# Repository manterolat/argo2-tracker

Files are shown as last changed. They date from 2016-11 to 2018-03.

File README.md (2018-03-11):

# Argo 2 Tracker

High Altitude Balloon tracker designed for the Argo 2 launch by the Near Space Program at the International School of Panama.

Tracker transmits temperature, pressure and humidity data, as well as location coordinates and other status information.

The GroundStation program shows any data received, along with signal strength and CRC checking. It can also upload new data to the online tracker at [HabHub](https://tracker.habhub.com).

Included are the PCB schematics (made in Eagle CAD) and software of the tracker and receiver, as well as the Ground Station program which runs on the tracking computer.

The software for the tracker and receiver is written in Arduino / C++, while the Ground Station written in Python.

## Table of Contents
 * [Parts and Components](#parts)
 * [Installation](#installation)
 * [Usage](#usage)
 * [Testing](#testing)
 * [Printed Circuit Boards](#pcbs)
 * [Launches](#launch)

## Parts and Components
### Tracker:
 * [Adafruit Feather M0](https://www.adafruit.com/product/269), or [Teensy 3.x](https://www.pjrc.com/store/teensy32.html) with [Feather adapter](https://www.adafruit.com/products/3200)
 * U-Blox NEO 6/7/8 Serial GPS module such as [this](https://www.amazon.com/Antenna-AeroQuad-Multirotor-Quadcopter-Aircraft/dp/B00RCP9MLY/)
 * ~~[MAX31855 thermocouple amplifier](https://www.adafruit.com/products/269) (and [thermocouple](https://www.adafruit.com/products/270))~~ Doesn't work
 * [BME280 module](https://www.adafruit.com/products/2652): Pressure, humidity and temperature sensor
 * RFM95W Transceiver

### Receiver:
 * [Adafruit Feather M0](https://www.adafruit.com/product/269)
 * RFM95W Transceiver
 * PCB SMA connector (if using SMA cable for antenna)

## Installation
To download the files in this repository run:

`git clone https://github.com/manterolat/argo2-tracker.git`

### Tracker:
#### Software
 * [Arduino IDE](https://www.arduino.cc/en/Main/Software) (1.6.0 and above should work)
 * If using *Teensy 3.x*: Install [Teensyduino](http://www.pjrc.com/teensy/teensyduino.html) (tested with Teensyduino 1.29)
 * If using *Feather M0*: follow [these](https://learn.adafruit.com/adafruit-feather-m0-basic-proto/setup) instructions

#### Arduino Libraries
 * [Adafruit Unified Sensor Driver](https://github.com/adafruit/Adafruit_Sensor)
 * [Adafruit BME280](https://github.com/adafruit/Adafruit_BME280_Library)
 * ~~Only with *Teensy* setup: [Adafruit MAX31855](https://github.com/adafruit/Adafruit-MAX31855-library) (version 1.0.3 or higher for SPI Transactions)~~ Doesn't work
 * If using *Teensy 3.x*: [RadioHead](https://github.com/PaulStoffregen/RadioHead) (Paul Stoffregen's version for Teensy)
 * If using *Feather M0*: [RadioHead](http://www.airspayce.com/mikem/arduino/RadioHead/) (Regular, updated version) 
 * ~~[TinyGPS++](https://github.com/mikalhart/TinyGPSPlus)~~ Broken for non-AVR chips: use [this](https://github.com/manterolat/argo2-tracker/files/601752/TinyGPSPlus.zip) modified version instead

### Receiver:
#### Software
 * [Arduino IDE](https://www.arduino.cc/en/Main/Software) (1.6.0 and above should work)

#### Arduino Libraries
 * [RadioHead](https://github.com/PaulStoffregen/RadioHead)

### Ground Station:
GroundStation runs on Python 2.7, and requires the following modules:
 * *crcmod* for CRC checking
 * *pyqrcode* for generating QR codes
 * *pyserial* for serial communication

To install these (using *pip*) run:

`pip install crcmod pyqrcode pyserial`

## Usage
After setting up the software and libary requirements you should be able to upload the tracker and receiver programs, as well as run the Ground Station.

### Tracker:
Open `/src/Argo2_Tracker/Argo2_Tracker.ino` in the Arduino IDE.

Before compiling and uploading to the Feather/Teensy make sure to configure the tracker by changing the following lines in the program: 
```C++
// Tracker callsign: change to your tracker's callsign
#define CALLSIGN "CHANGE_ME"

// Debug messages: uncomment the following line to enable printing to serial (for testing purposes)
//#define DEBUG

...

// Select either Teensy 3.x or Feather M0
#define TEENSY
//#define FEATHER
```

Leaving `#define DEBUG` uncommented will compile the Serial messages, which takes up space and cycles in the microcontroller.

Finally, select the board type and serial port in the Arduino IDE and upload.  

### Receiver:
Open `Argo2_Receiver.ino` with the Arduino IDE, then select the Feather M0 from the boards list and upload.

### Ground Station:
If running on macOS with Python 2 installed manually, double-clicking `GroundStation.py` should start the program.

Otherwise, open a terminal in the argo2-tracker directory and run:

```bash
cd GroundStation
python GroundStation.py
```

The program will keep a log in the form of files: `GroundStation.log` and `sentences.log`.

**Caution: Don't toggle the _Online_ checkbox until you have setup your tracker on [HabHub](https://tracker.habhub.com) and are ready to launch/test.**

## Testing
Things to keep in mind before launch:
 * *Cut the thermocouple cable as short as possible* while keeping a small piece outside. We found that this reduced interference and/or resistance in the cable and improved the accuracy of measurements.
 * For the BME280 (pressure and humidity sensor) it's best to use cables and *place the module on the outside of the capsule*.
 * If placing the BME280 outside, *cover the sensor with a small piece of cotton/fabric using tape* in order to block wind which could affect measurements.

Only the *Adafruit Feather M0* configuration (without thermocouple sensor) has being tested so far. Since then there have been a few changes to the tracker and receiver programs (mostly changing Serial.println to Snprintln).

The tracker also can't use the BME280 through SPI at the same time as the RFM95W radio due to SPI Transaction issues with the RadioHead library.
For this reason, **to use the BME280 you will need to connect the SCL and SDA pins of the BME280 to those of the Feather externally to use I2C instead** (soldering wires externally).

## Printed Circuit Boards
Both of these boards can be used with headers (for removable/replaceable components), or with the components soldered directly unto the board. I recommend the first method.

If using headers note that the RFM95W module needs *2.0mm* headers, instead of regular 2.54mm headers.

The PCBs used in the Argo 2 launch were printed by [OSH Park](https://oshpark.com/) and functioned perfectly.

### Tracker:
Note that there is an issue with the buzzer MOSFET and its connections at the moment. If you plan to use this board with a buzzer, you will have to either fix the MOSFET connections or connect the components separately.

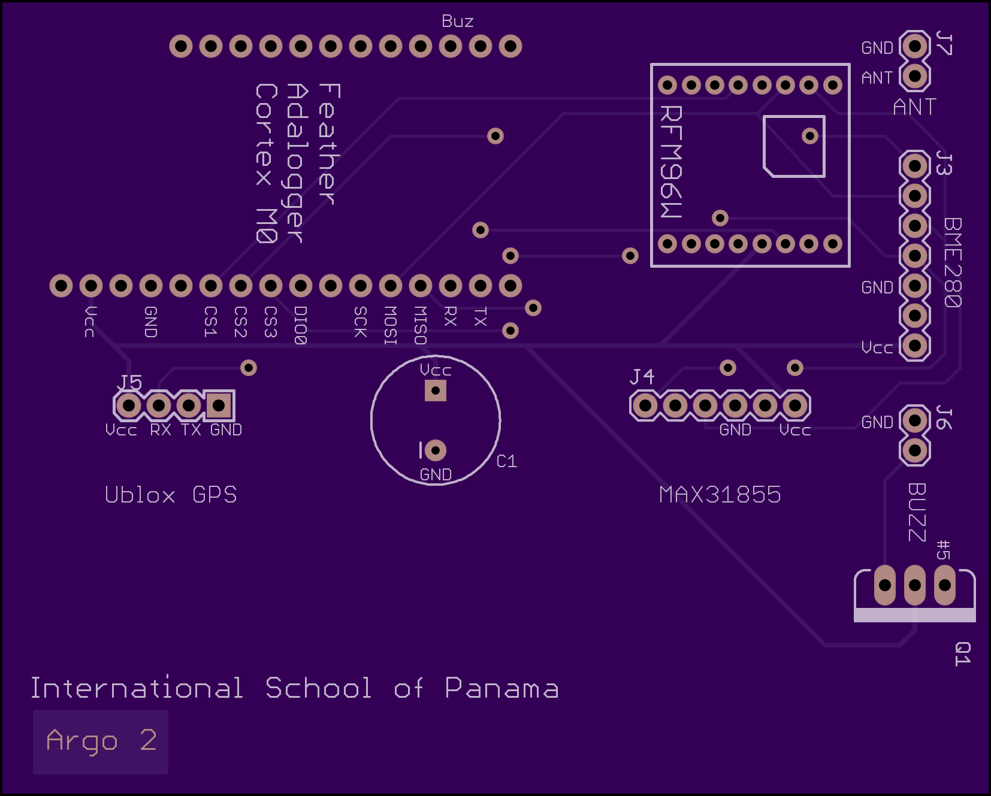
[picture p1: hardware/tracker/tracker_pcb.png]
 

### Receiver:
This board supports the use of a PCB to SMA adapter if needed.

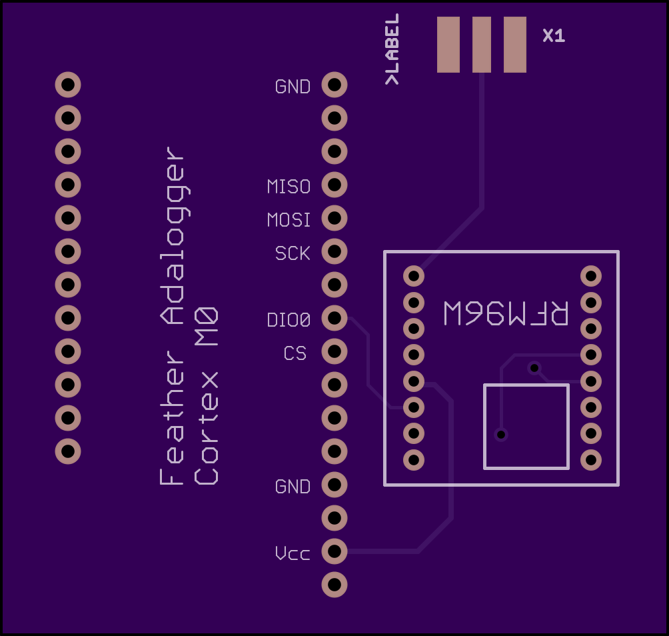
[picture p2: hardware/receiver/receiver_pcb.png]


## Launches
### **April 23, 2016**: (Argo-2) 
We launched the Argo 2 capsule on April 23, 2016 using the Feather M0 setup without the thermocouple (due to SPI issues). We received data throughout most of flight, which reached `33 km` altitude, and used HabHub to follow the capsule.
Unfortunately, the capsule landed in a mountainous area that made recovery impossible.

The data revealed an average vertical speed of `2.3 m/s` (very low) and an estimated flight time of 295 minutes.

### **November 28, 2016**: (CP-1)

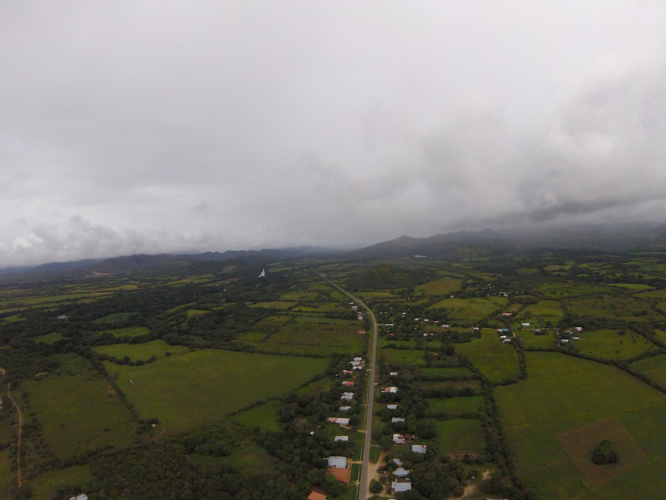
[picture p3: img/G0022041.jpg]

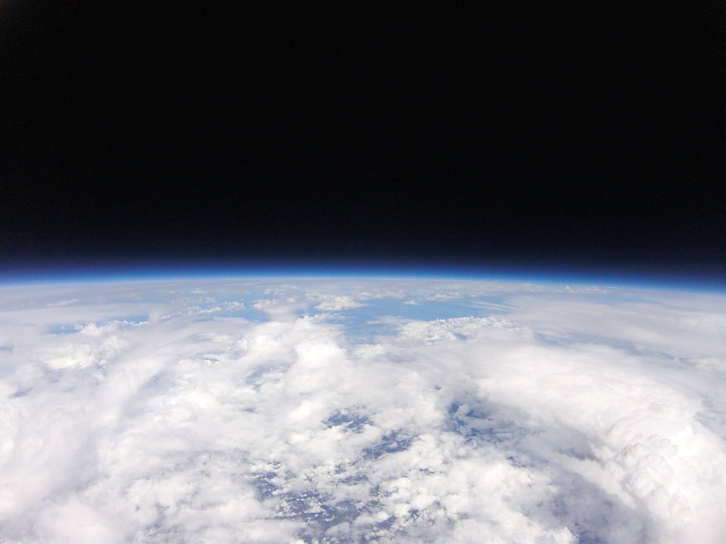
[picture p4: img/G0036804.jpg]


We launched the CP-1 capsule on November 28, 2016, and succesfully recovered it! GoPro camera took many photos throughout the mission.

The capsule rose to around `33 km` at an average vertical speed of `4.5 m/s`. The mission lasted 149 minutes.

### **June 4, 2017**: (CP-2)
Another successfull recovery with the same setup!

The capsule rose to around `27 km` at an average vertical speed of `5.5 m/s`. The mission lasted 136 minutes.

In the future, the NSP team will be using the [Pi in the Sky](http://www.pi-in-the-sky.com/) board due to its widespread support and easy configurability. I wish them the best of luck in future launches!

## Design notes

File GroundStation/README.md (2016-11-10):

# Argo 2 Ground Station

This is the Ground Station program used to receive, interpret, display and upload messages from the tracker.

The program connects to the receiver through a serial port (USB) and will display messages received.
There is also the option to send received data to [HabHub](https://tracker.habhub.com). It also allows the user to send configuration messages (custom or prepared) to the tracker.

Additionally, the application checks incoming messages for errors and displays latest tracker data in a table. It also allows the user to see the last received location of the tracker through Google Maps and a geolocation-encoded QR code. 

## Table of Contents

 * [Installation](#installation)
 * [Usage](#usage)
 * [Instructions](#instructions)

## Installation
To download the files in this repository run:

`git clone https://github.com/manterolat/argo2-tracker.git`

GroundStation runs on Python 2.7, and requires the following modules:
 * *crcmod* for CRC checking
 * *pyqrcode* for generating QR codes
 * *pyserial* for serial communication

To install these (using *pip*) run:

`pip install crcmod pyqrcode pyserial`

## Usage
If running on macOS with Python 2 installed manually, double-clicking `GroundStation.py` should start the program.

Otherwise, open a terminal in the argo2-tracker directory and run:

```bash
cd GroundStation
python GroundStation.py
```

The program will keep a log in the form of files: `GroundStation.log` and `sentences.log`.

**Caution: Don't toggle the _Online_ checkbox until you have setup your tracker on [HabHub](https://tracker.habhub.com) and are ready to launch/test.**

## Instructions
Once the Ground Station is running you will need to connect to the receiver and configure your callsign (if sending data to HabHub).

 1. Connect your receiver through a USB port. Make sure that you have uploaded the receiver program to the microcontroller.
 
 2. Click on the *Port* dropdown list and select your receiver. On Windows it will have a name such as `COM3`. On Linux and Mac it will likely be similar to `/dev/tty.*`.

 3. *If uploading data to [HabHub](https://tracker.habhub.com):* decide on a unique callsign and set it by clicking the *Set callsign* button.

 4. Any data received will be displayed in the main output box. To view the parsed data click on the *Show Status Window* button. A new window will open with a table containing the latest data received.

 5. Besides using HabHub, you can view the current location of the tracker by either scanning the **QR code** displayed on the main screen with a camera-enabled mobile device (which should automatically open a mapping app), or by going to `Tracking->Google Maps` on the menu toolbar (to open Google Maps on a browser window).

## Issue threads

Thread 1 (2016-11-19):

BME280 using I2C instead of SPI in Teensy tracker

manterolat, 2016-11-19:
Tracker program initializes BME280 sensor through _I2C_ rather than _SPI_ when using Teensy.

The tracker PCB connects pins required for *SPI* to the BME280, not the _I2C_ **SCL** and **SDA** pins.
This means that all tracker programs since the initial commit will fail to initialize the BME280 and stop execution.

Can be fixed by changing the Adafruit BME280 library initialization/constructor to use SPI.

I2C Initialization (won't work without external wiring):
```c++
Adafruit_BME280 bme;
```

SPI Initialization (works with Teensy, not Feather M0):
```c++
Adafruit_BME280 bme(BME_CS);
```

Note: the Feather M0 has problems with SPI Transactions, meaning that the BME280 **has** to be connected externally through I2C. Another solution would be to add Cortex M0 support to the RadioHead library (SPI Transactions version).

manterolat, 2016-11-19:
After testing it has been determined that the RFM95W does not allow for any other SPI devices to be used.

The radio probably does not follow SPI specifications and the BME280 will have to be connected through I2C. This also means that the MAX31855 won't be used/supported.

Closed 2016-11-19.

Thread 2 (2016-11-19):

Pin assignment for Teensy with Feather adapter incorrect

manterolat, 2016-11-19:
The _Teensy 3.x to Feather_ adapter changes many of the pin numbers used by the sensors/radio. The current tracker program doesn't use these new pins if the Teensy is being used, meaning that it can't communicate with the sensors and radio.

Fixing this involves defining pins differently depending on whether the Feather or Teensy is being used.

Closed 2016-11-19.

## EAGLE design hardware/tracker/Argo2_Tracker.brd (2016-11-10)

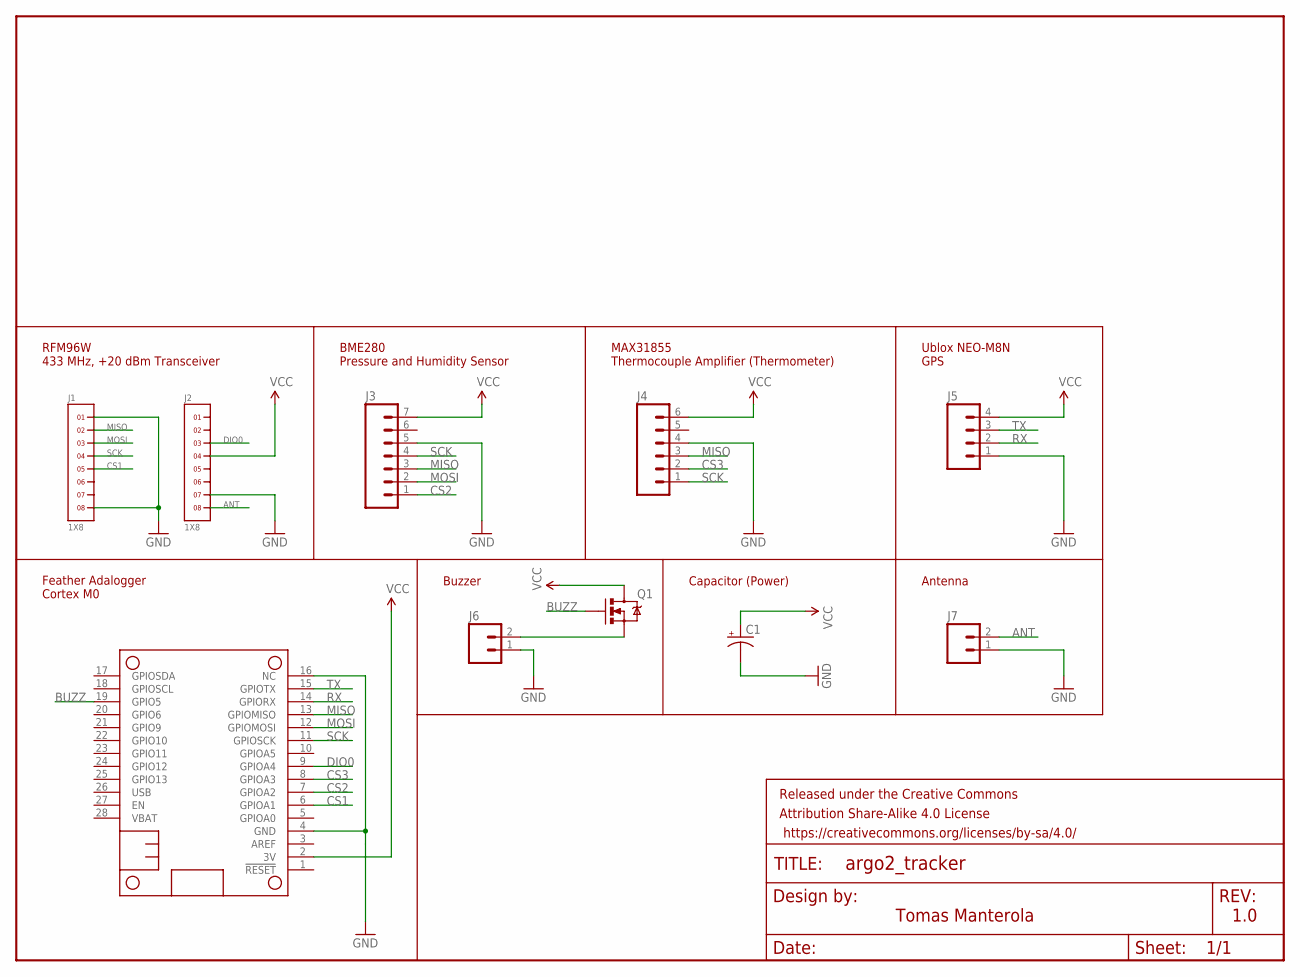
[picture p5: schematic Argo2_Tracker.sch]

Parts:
C1: CAP_POLPTH4; CPOL-RADIAL-1000UF-25V
FRAME1: FRAME-LETTERNO_PACKAGE; DUMMY
J1, J2: 1X8
J3: M07; 1X07
J4: M06SILK_FEMALE_PTH; 1X06
J5: M041X04_NO_SILK; 1X04_NO_SILK
J6, J7: M02PTH; 1X02
MS1: FEATHERWING_NODIM; FEATHERWING_DIM
Q1: MOSFET-NCHANNELFQP30N06L; TO220V

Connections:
ANT: J2.8, J7.2
BUZZ: MS1.19 (GPIO5), Q1.1 (G)
CS1: J1.5, MS1.6 (GPIOA1)
CS2: J3.1, MS1.7 (GPIOA2)
CS3: J4.2, MS1.8 (GPIOA3)
DIO0: J2.3, MS1.9 (GPIOA4)
GND: C1.2 (-), J1.1, J1.8, J2.7, J3.5, J4.4, J5.1, J6.1, J7.1, MS1.4 (GND), MS1.16 (NC)
MISO: J1.2, J3.3, J4.3, MS1.13 (GPIOMISO)
MOSI: J1.3, J3.2, MS1.12 (GPIOMOSI)
unnamed: J6.2, Q1.3 (S)
RX: J5.2, MS1.14 (GPIORX)
SCK: J1.4, J3.4, J4.1, MS1.11 (GPIOSCK)
TX: J5.3, MS1.15 (GPIOTX)
VCC: C1.1 (+), J2.4, J3.7, J4.6, J5.4, MS1.2 (3V), Q1.2 (D)

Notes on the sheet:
RFM96W 433 MHz, +20 dBm Transceiver
Tomas Manterola
1.0
Feather Adalogger Cortex M0
BME280 Pressure and Humidity Sensor
MAX31855 Thermocouple Amplifier (Thermometer)
Ublox NEO-M8N GPS
Buzzer
Antenna
Capacitor (Power)

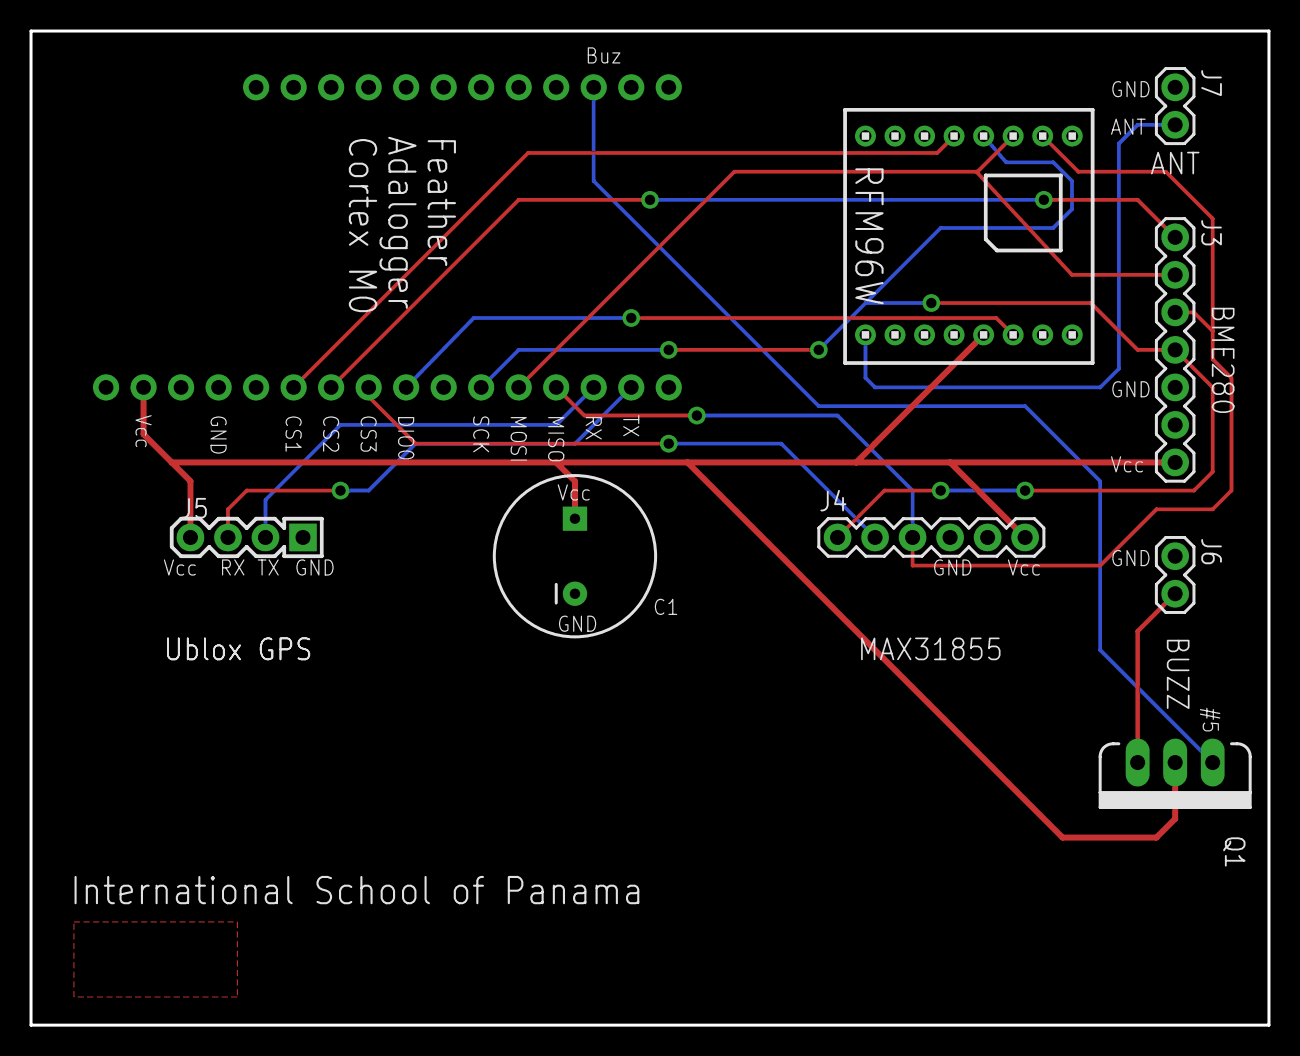
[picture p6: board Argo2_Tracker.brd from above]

Board: 2 copper layers, 83.8 x 67.3 mm, 11 parts (0 on the bottom side), 14 nets.

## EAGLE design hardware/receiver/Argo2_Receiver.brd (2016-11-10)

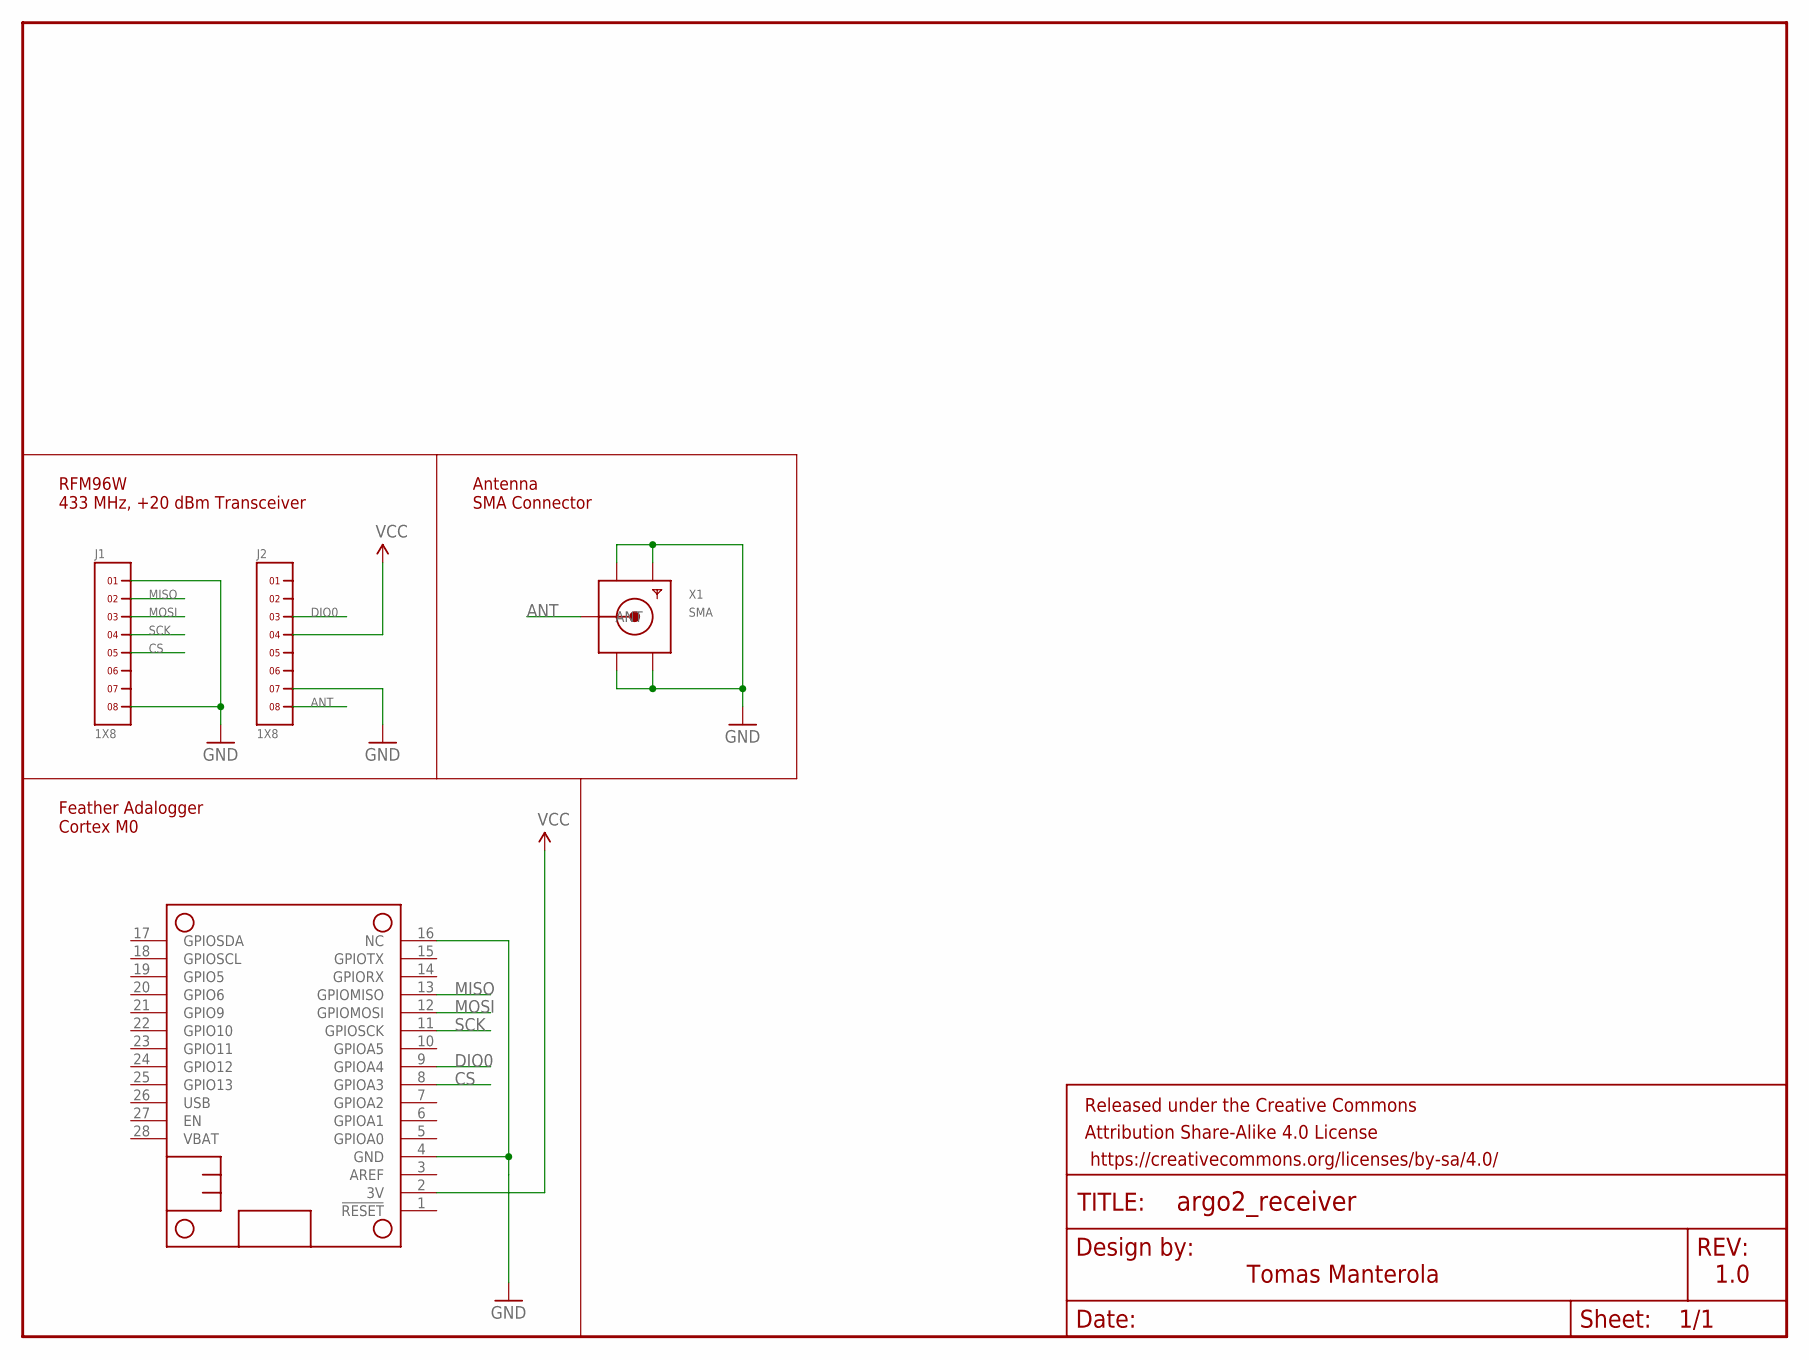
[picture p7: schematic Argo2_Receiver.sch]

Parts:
FRAME1: FRAME-LETTERNO_PACKAGE; DUMMY
J1, J2: 1X8
MS1: FEATHERWING_NODIM; FEATHERWING_DIM
X1: SMA; SMA_EDGELAUNCH

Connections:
ANT: J2.8, X1.P (ANT)
CS: J1.5, MS1.8 (GPIOA3)
DIO0: J2.3, MS1.9 (GPIOA4)
GND: J1.1, J1.8, J2.7, MS1.4 (GND), MS1.16 (NC), X1.GND@1 (GND4), X1.GND@2 (GND3), X1.GND@3 (GND2), X1.GND@4 (GND1)
MISO: J1.2, MS1.13 (GPIOMISO)
MOSI: J1.3, MS1.12 (GPIOMOSI)
SCK: J1.4, MS1.11 (GPIOSCK)
VCC: J2.4, MS1.2 (3V)

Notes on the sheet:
RFM96W 433 MHz, +20 dBm Transceiver
Tomas Manterola
1.0
Feather Adalogger Cortex M0
Antenna SMA Connector

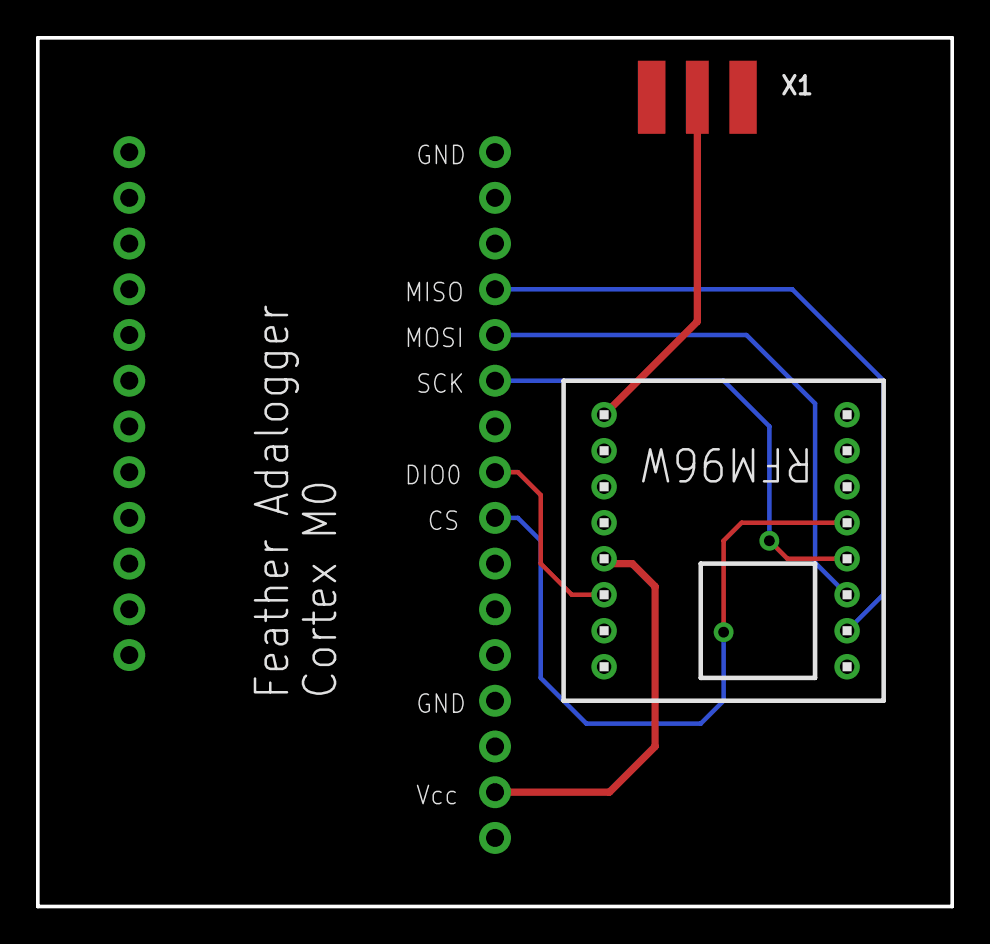
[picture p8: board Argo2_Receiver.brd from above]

Board: 2 copper layers, 50.8 x 48.3 mm, 5 parts (0 on the bottom side), 8 nets.

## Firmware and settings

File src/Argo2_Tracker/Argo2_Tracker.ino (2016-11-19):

/* Argo 2 Tracker
 *
 * Tomas Manterola
 *
 * Sources:
 * https://adafruit.com/
 * https://stackoverflow.com/
 * https://ukhas.org.uk/
 *
 * Tracker program to run on a Teensy 3.1/3.2 or Adafruit Feather M0 for HAB use.
 * Transmits data including: Internal/External Temperature, Pressure and Humidity.
 * Uses RFM96W LoRa transciever to send telemetry data back to Ground Station.
 * Uses a U-Blox NEO-M8N GPS module in order to track location and altitude.
 *
 * Uses Adafruit libraries for the BME280 and MAX31855 sensors
 * Uses Radiohead library for RFM96W radio (requires SPI Transaction version)
 *
 * Sample TX message: ARGO2,10000,22:22:22,-92.1232322,-90.2322323,30000,-12.0,12.0,32.4,-20.25,-10.1,300.0,56.4,4.32,10,5,1*b762;-50
 * Sample RX message: 1,0*BEEF
 */


/*** Tracker Configuration ***/

// Tracker callsign: change to your tracker's callsign and uncomment
//#define CALLSIGN "CHANGE_ME"
#ifndef CALLSIGN
    #error Callsign must be set before use!
#endif

// Debug messages: comment the following line to disable printing to serial (for testing purposes)
#define DEBUG

// Source: http://arduino.stackexchange.com/questions/9857/can-i-make-the-arduino-ignore-serial-print
#ifdef DEBUG
    #define Sprintln(a) (Serial.println(a))
    #define Sprint(a) (Serial.print(a))
#else
    #define Sprintln(a)
    #define Sprint(a)
#endif

// Select either Teensy 3.x or Feather M0
//#define TEENSY
#define FEATHER

// Enable MAX31855 thermocouple: can be disabled by commenting MAX31855 line
#ifdef TEENSY
    //#define MAX31855
#endif


/*** Includes ***/

#include <SPI.h>
#include <Wire.h>

#include <Adafruit_Sensor.h>
#include <Adafruit_BME280.h>
#include <RH_RF95.h>
#include <TinyGPS++.h>

#ifdef MAX31855
    #include <Adafruit_MAX31855.h>
#endif


/*** Configuration of Sensors, GPS and Radio ***/

// Indicator LEDs
#define LED 13

// Battery voltage pin
#define BATT A7

// Buzzer pin
#ifdef TEENSY
    #define BUZZ 8
#else
    #define BUZZ 5
#endif

// Adafruit BME280 Sensor - Uses I2C
// Note: if using I2C you must connect the SCL and SDA pins of the BME280 to the microcontroller externally
#ifdef TEENSY
    #define BME_CS A3
    Adafruit_BME280 bme;
#else
    #define BME_CS A2
    Adafruit_BME280 bme;
#endif

// Adafruit MAX31855K Thermocouple Amplifier - Uses SPI
#ifdef TEENSY
    #define MAX_CS A1
#else
    #define MAX_CS A3
#endif

#ifdef MAX31855
    Adafruit_MAX31855 thermocouple(MAX_CS);
#endif

// RFM96W Transceiver - uses propietary LoRa radio protocol and transmits between 410.000 and 525.000 MHz
// Uses SPI - RFM96W Chip Select and Interrupt pins
#ifdef TEENSY
    #define RFM_CS A2
    #define RFM_INT A0
#else
    #define RFM_CS A1
    #define RFM_INT 18 // or A4
#endif
RH_RF95 rf95(RFM_CS, RFM_INT);

// U-Blox NEO-M8N GPS - uses Serial1
// U-Blox GPS data parser - TinyGPSPlus
TinyGPSPlus gpsParser;


/*** Constants and U-Blox Commands ***/

// States
#define STATE_STANDBY       0
#define STATE_RISING        1
#define STATE_FALLING_HIGH  2
#define STATE_FALLING_LOW   3
#define STATE_LANDING       4

// Commands that can be sent from ground
#define COMMAND_ID_TX_POWER     0
#define COMMAND_ID_GPS_MODE     1
#define COMMAND_ID_GPS_POWER    2
#define COMMAND_ID_BUZZER       3
#define COMMAND_ID_MODE         4

#define COMMAND_VALUE_GPS_MODE_PED 0
#define COMMAND_VALUE_GPS_MODE_AIR 1

#define COMMAND_VALUE_GPS_POWER_MAX 0
#define COMMAND_VALUE_GPS_POWER_SAV 1

#define COMMAND_VALUE_BUZZER_OFF 0
#define COMMAND_VALUE_BUZZER_ON  1

// U-Blox Command: Disable GPGLL NMEA Sentence
const uint8_t GPS_DISABLE_GPGLL[] {
    0xB5, 0x62, 0x06, 0x01, 0x08, 0x00, 0xF0, 0x01, 0x00, 0x00, 0x00, 0x00, 0x00, 0x01, 0x01, 0x2B
};

// U-Blox Command: Disable GPGSA NMEA Sentence
const uint8_t GPS_DISABLE_GPGSA[] = {
    0xB5, 0x62, 0x06, 0x01, 0x08, 0x00, 0xF0, 0x02, 0x00, 0x00, 0x00, 0x00, 0x00, 0x01, 0x02, 0x32
};

// U-Blox Command: Disable GPGSV NMEA Sentence
const uint8_t GPS_DISABLE_GPGSV[] = {
    0xB5, 0x62, 0x06, 0x01, 0x08, 0x00, 0xF0, 0x03, 0x00, 0x00, 0x00, 0x00, 0x00, 0x01, 0x03, 0x39
};

// U-Blox Command: Set Navigation Mode to 'Airborne < 1G' (Large Deviation)
// For altitudes > 9 km
const uint8_t GPS_MODE_AIRBORNE[] = {
    0xB5, 0x62, 0x06, 0x24, 0x24, 0x00, 0xFF, 0xFF, 0x06, 0x03, 0x00, 0x00, 0x00, 0x00, 0x10, 0x27, 0x00, 0x00,
    0x05, 0x00, 0xFA, 0x00, 0xFA, 0x00, 0x64, 0x00, 0x2C, 0x01, 0x00, 0x00, 0x00, 0x00, 0x00, 0x00, 0x00, 0x00,
    0x00, 0x00, 0x00, 0x00, 0x00, 0x00, 0x16, 0xDC
};

// U-Blox Command: Set Navigation Mode to 'Pedestrian' (Small Deviation)
// For altitudes < 9 km
const uint8_t GPS_MODE_PEDESTRIAN[] = {
    0xB5, 0x62, 0x06, 0x24, 0x24, 0x00, 0xFF, 0xFF, 0x03, 0x03, 0x00, 0x00, 0x00, 0x00, 0x10, 0x27, 0x00, 0x00,
    0x05, 0x00, 0xFA, 0x00, 0xFA, 0x00, 0x64, 0x00, 0x2C, 0x01, 0x00, 0x00, 0x00, 0x00, 0x00, 0x00, 0x00, 0x00,
    0x00, 0x00, 0x00, 0x00, 0x00, 0x00, 0x13, 0x76
};

// U-Blox Command: Set to Power Saving Mode
// This mode requires a GPS Fix with >5 satellites (otherwise stability issues may arise)
const uint8_t GPS_POWER_SAVING[] = {
    0xB5, 0x62, 0x06, 0x11, 0x02, 0x00, 0x08, 0x01, 0x22, 0x92
};

// U-Blox Command: Set to Max Performance Mode (default)
const uint8_t GPS_POWER_PERFORMANCE[] = {
    0xB5, 0x62, 0x06, 0x11, 0x02, 0x00, 0x08, 0x00, 0x21, 0x91
};


/*** Global Variables ***/

// Should Buzzer be on
bool buzzerOn = false;
bool buzzerState = false;

// Used to calculate and store vertical speed of capsule
double lastAltitude = 0;
double verticalSpeed = 0;

// Used to confirm that a message was received from ground by capsule
// Shows # of messages received since last transmission (reset to 0 after transmitting)
uint8_t rxACK = 0;

// TX Power: from 5 - 23 (measured in dBm)
uint8_t txPower = 23;

// Buffers to store messages to be received/transmitted (max length is 255 - 4 = 251)
uint8_t rxMsg[RH_RF95_MAX_MESSAGE_LEN];
uint8_t txMsg[RH_RF95_MAX_MESSAGE_LEN];

// Used to control when data is collected/transmitted
// Keeps track of the time in seconds (0 - 59) and minutes (0 - 59)
uint8_t currTimeSec = -1;
uint8_t currTimeMin = -1;
uint8_t currTimeHour = -1;

// Assures that a message hasn't already been sent in the same second
uint8_t lastTimeSec = -1;
uint8_t lastTimeMin = -1;

// Interval of seconds after which a message should be sent
uint8_t interval = 30;

// Buzzer interval (milliseconds), period (milliseconds) and last time on (milliseconds)
uint32_t buzzInterval = 5000;
uint32_t buzzPeriod = 1000;
uint32_t buzzLastOn = 0;

// Sentence ID (number of sentences sent)
uint32_t sentID = 1;

// Save GPS status
uint8_t gpsMode = 0;
uint8_t gpsPower = 0;

// Status - Shows information about program
uint8_t status[7];

// State - Current mode/state of tracker (based on altitude and vertical speed)
uint8_t state = 0;


/*** Functions ***/

// Setup pins, sensors and radio
// Runs only on startup
void setup() {
    
    /*** Serial and Output Pin Setup ***/

    #ifdef DEBUG
        // Start serial communication with computer for debugging
        Serial.begin(9600);

        // Wait until computer catches up connecting to Serial
        delay(5000);
    #endif

    // Configure LED, Buzzer and CS pin to OUTPUT
    pinMode(LED, OUTPUT);
    pinMode(BUZZ, OUTPUT);
    pinMode(BME_CS, OUTPUT);
    pinMode(MAX_CS, OUTPUT);
    pinMode(RFM_CS, OUTPUT);

    // Start serial communication with U-Blox GPS
    Serial1.begin(9600);


    /*** Setup GPS, BME280 and RFM96W ***/

    // Set U-Blox Nav Mode to 'Airborne < 1G' and Power Mode to 'Max Power' (retry until correct ACK received)
    Sprint("Setting GPS to Flight Mode...\t");
    setGPSMode(COMMAND_VALUE_GPS_MODE_AIR);
    setGPSPower(COMMAND_VALUE_GPS_POWER_MAX);
    Sprintln("OK!");

    // Disable unnecessary NMEA sentences being sent by U-Blox GPS
    Sprint("Disabling GPS sentences...\t");

    bool gpsSetSuccess = false;
    while (!gpsSetSuccess) {
        sendUBX(GPS_DISABLE_GPGLL, sizeof(GPS_DISABLE_GPGLL) / sizeof(uint8_t));
        gpsSetSuccess = getUBX_ACK(GPS_DISABLE_GPGLL);
    }

    gpsSetSuccess = false;
    while (!gpsSetSuccess) {
        sendUBX(GPS_DISABLE_GPGSA, sizeof(GPS_DISABLE_GPGSA) / sizeof(uint8_t));
        gpsSetSuccess = getUBX_ACK(GPS_DISABLE_GPGSA);
    }

    gpsSetSuccess = false;
    while (!gpsSetSuccess) {
        sendUBX(GPS_DISABLE_GPGSV, sizeof(GPS_DISABLE_GPGSV) / sizeof(uint8_t));
        gpsSetSuccess = getUBX_ACK(GPS_DISABLE_GPGSV);
    }

    Sprintln("OK!");

    // Initialize BME280
    Sprint("Starting BME280 Sensor...\t");
    if (!bme.begin()) {
        Sprintln("ERROR");

        // If it can't be initialized, stop the program and blink every 1s
        while (true) {
            digitalWrite(BUZZ, !digitalRead(BUZZ));
            delay(1000);
        }
    }
    Sprintln("OK!");

    // Initialize RFM96W - if there's an error retry
    while (!rf95.init()) {
        Sprintln("RFM96W Initialization Failed!");
        digitalWrite(BUZZ, HIGH);
        delay(1000);
        digitalWrite(BUZZ, LOW);
    }

    // Configure RFM96W and set it to receiver mode so that it can receive messages
    configureRFM96W();
    rf95.setModeRx();

    // Wait until U-Blox GPS has a fix (5 or more satellites) before starting main program
    Sprint("Waiting for GPS Fix...\t\t");
    while (gpsParser.satellites.value() < 5) {
        while (Serial1.available()) {
            gpsParser.encode(Serial1.read());
        }
    }
    Sprintln("OK!");

    // Save 'lastAltitude' for vertical velocity calculation
    lastAltitude = gpsParser.altitude.meters();
}


// Manage state/status, GPS updates, reception and transmission - repeat forever
void loop() {

    // Update current time in seconds (0 - 59) and minutes (0 - 59)
    currTimeMin = gpsParser.time.minute();
    currTimeSec = gpsParser.time.second();


    /*** Status / State ***/

    // State: current state of tracker
    //  0. Standby (on ground)
    //      TX_POWER:   23
    //      GPS_MODE:   Airborne
    //      GPS_POWER:  MAX
    //      BUZZER:     OFF
    //
    //  1. Rising (vertical speed > 2.0 m/s and altitude > 500 m)
    //      TX_POWER:   23
    //      GPS_MODE:   Airborne
    //      GPS_POWER:  MAX
    //      BUZZER:     OFF
    //
    //  2. Falling (vertical speed < -2.0)
    //      TX_POWER:   23
    //      GPS_MODE:   Airborne
    //      GPS_POWER:  MAX
    //      BUZZER:     OFF
    //
    //  3. Falling, Low ALitude (vertical speed < -2.0 and altitude < 9,000 m)
    //      TX_POWER:   23
    //      GPS_MODE:   Pedestrian
    //      GPS_POWER:  MAX
    //      BUZZER:     OFF
    //
    //  4. Landing (vertical speed < 1.0 and altitude < 2,000 m)
    //      TX_POWER:   23
    //      GPS_MODE:   Pedestrian
    //      GPS_POWER:  MAX
    //      BUZZER:     ON

    switch (state) {

        // On ground. Check if we have launched (going up).
        case STATE_STANDBY:

            // If vertical speed is greater than 2 m/s and altitude is greater than 500 m, switch to RISING state
            if (verticalSpeed > 2.0 && gpsParser.altitude.meters() > 500.0) {
                state = STATE_RISING;

                txPower = 23;

                if (gpsMode != COMMAND_VALUE_GPS_MODE_AIR) {
                    setGPSPower(COMMAND_VALUE_GPS_MODE_AIR);
                }

                if (gpsPower != COMMAND_VALUE_GPS_POWER_MAX) {
                    setGPSMode(COMMAND_VALUE_GPS_POWER_MAX);
                }

                buzzerOn = false;
            }

            break;

        // Rising. Check if falling.
        case STATE_RISING:

            // If vertical speed is less than -2 m/s, switch to FALLING_HIGH state.
            if (verticalSpeed < -2.0) {
                state = STATE_FALLING_HIGH;

                txPower = 23;

                if (gpsMode != COMMAND_VALUE_GPS_MODE_AIR) {
                    setGPSPower(COMMAND_VALUE_GPS_MODE_AIR);
                }

                if (gpsPower != COMMAND_VALUE_GPS_POWER_MAX) {
                    setGPSMode(COMMAND_VALUE_GPS_POWER_MAX);
                }

                buzzerOn = false;
            }

            break;

        // Falling (altitude higher than 9,000 m). Check if we are below 9,000 m.
        case STATE_FALLING_HIGH:

            // If vertical speed is less than -2 m/s and altitude is less than 9,000 m, switch to FALLING_LOW state.
            if (verticalSpeed < -2.0 && gpsParser.altitude.meters() < 9000.0) {
                state = STATE_FALLING_LOW;

                txPower = 23;

                if (gpsMode != COMMAND_VALUE_GPS_MODE_AIR) {
                    setGPSPower(COMMAND_VALUE_GPS_MODE_AIR);
                }

                if (gpsPower != COMMAND_VALUE_GPS_POWER_MAX) {
                    setGPSMode(COMMAND_VALUE_GPS_POWER_MAX);
                }

                buzzerOn = false;
            }

            break;

        // Falling (altitude lower than 9,000 m). Check if we are below 2,000 m.
        case STATE_FALLING_LOW:

            // If altitude is lower than 2,000 m, switch to LANDING state
            if (gpsParser.altitude.meters() < 2000.0) {
                state = STATE_LANDING;

                txPower = 23;

                if (gpsMode != COMMAND_VALUE_GPS_MODE_PED) {
                    setGPSPower(COMMAND_VALUE_GPS_MODE_PED);
                }

                if (gpsPower != COMMAND_VALUE_GPS_POWER_MAX) {
                    setGPSMode(COMMAND_VALUE_GPS_POWER_MAX);
                }

                buzzerOn = true;
            }

            break;

        // Landing (altitude lower than 2,000).
        case STATE_LANDING:
            if (verticalSpeed < 0.2) {

            }

            break;
    }

    // Status - shows current functioning of the tracker
    // [STATE][TX_POWER][GPS_MODE][GPS_POWER][BUZZER]
    // Example: 113100 -> State: 1, TX Power: 13, GPS Mode: 1, GPS Power: 0, Buzzer: 1
    sprintf((char*)status, "%u%02u%u%u%d", state, txPower, gpsMode, gpsPower, buzzerOn);


    /*** Get GPS Data ***/

    // Read data from U-Blox GPS and pass it to parser
    while (Serial1.available()) {
        gpsParser.encode(Serial1.read());
    }

        
    /*** Receive Messages ***/

    // Check for messages from ground - Format of message: [MSG]*[CHKSUM]
    if (rf95.available()) {
        uint8_t len = sizeof(rxMsg);

        // Receive data and check for errors ('rf95.recv(data, &len)' returns 0 if error occurs)
        if (rf95.recv(rxMsg, &len)) {
            Sprintln("Got new message!");

            do {

                /*** Parse Message ***/

                // Check that message is formatted correctly (lenght > 5 and contains '*')
                if (strlen((char*)rxMsg) > 5 && strchr((char*)rxMsg, '*') != NULL) {

                    char checksumRX[5];
                    char checksumCalc[5];

                    // Get checksum from last part of message
                    strncpy(checksumRX, ((char*)rxMsg + strlen((char*)rxMsg) - 4), 5);

                    // Calculate checksum from message (removing last 5 characters e.g: '*BEEF')
                    snprintf(checksumCalc, sizeof(checksumCalc), "%04X", calc_CRC16(rxMsg, strlen((char*)rxMsg) - 5));

                    // Compare received checksum with checksum calculated from message
                    if (strcmp(checksumRX, checksumCalc) == 0) {
                        Sprintln("Checksum is valid!");

                        // Acknowledge received message
                        rxACK++;

                        // Get ID and Value from message
                        char msgID[2];
                        char msgValue[3];

                        // Incoming messages can either be 3 or 4 characters in length (plus checksum: 5)
                        if (strlen((char*)rxMsg) == 3 + 5) {
                            strncpy(msgID, (char*)rxMsg, 1);
                            strncpy(msgValue, (char*)rxMsg + 2, 1);

                        } else if (strlen((char*)rxMsg) == 4 + 5) {
                            strncpy(msgID, (char*)rxMsg, 1);
                            strncpy(msgValue, (char*)rxMsg + 2, 2);
                        } else {
                            // Bad message - don't count it and exit
                            rxACK--;
                            break;
                        }
                        Sprint("ID: ");
                        Sprintln(msgID);
                        Sprint("Value: ");
                        Sprintln(msgValue);

                        // Convert string to int
                        uint8_t ID = atoi(msgID);
                        uint8_t value = atoi(msgValue);

                        // Find and run message
                        switch (ID) {

                            // Command to change TX Power to 'value'
                            case COMMAND_ID_TX_POWER:
                                if (value >= 5 || value <= 23) {
                                    txPower = value;

                                    Sprint("Setting TX_POWER to: ");
                                    Sprintln(value);
                                }
                                break;


                            case COMMAND_ID_GPS_MODE:
                                if (value == COMMAND_VALUE_GPS_MODE_PED) {
                                    setGPSMode(COMMAND_VALUE_GPS_MODE_PED);

                                } else if (value == COMMAND_VALUE_GPS_MODE_AIR) {
                                    setGPSMode(COMMAND_VALUE_GPS_MODE_AIR);

                                }
                                break;


                            case COMMAND_ID_GPS_POWER:
                                if (value == COMMAND_VALUE_GPS_POWER_MAX) {
                                    setGPSPower(COMMAND_VALUE_GPS_POWER_MAX);

                                } else if (value == COMMAND_VALUE_GPS_POWER_SAV) {
                                    setGPSPower(COMMAND_VALUE_GPS_POWER_SAV);

                                }
                                break;


                            case COMMAND_ID_BUZZER:
                                if (value == COMMAND_VALUE_BUZZER_OFF) {
                                    buzzerOn = false;

                                } else if (value == COMMAND_VALUE_BUZZER_ON) {
                                    buzzerOn = true;

                                }
                                break;

                            case COMMAND_ID_MODE:

                                switch (value) {

                                    case STATE_STANDBY:
                                        state = STATE_STANDBY;
                                        break;

                                    case STATE_RISING:
                                        state = STATE_RISING;
                                        break;

                                    case STATE_FALLING_HIGH:
                                        state = STATE_FALLING_HIGH;
                                        break;

                                    case STATE_FALLING_LOW:
                                        state = STATE_FALLING_LOW;
                                        break;

                                    case STATE_LANDING:
                                        state = STATE_LANDING;
                                        break;
                                        
                                }

                            default:
                                // Not a valid ID - revoke ACK
                                rxACK--;
                                break;
                        }

                    }
                }

            } while (false);

        } else {
            Sprintln("Error receiving message!");
        }
    }


    /*** Transmit Data and Location ***/

    // Check if it's time to collect/send data
    // If time is on interval and not the same time (sec or min different?) as last transmission, then collect/send
    if (currTimeSec % interval == 0 && (currTimeSec != lastTimeSec || currTimeMin != lastTimeMin)) {
        Sprintln("Sending Data!");

        // Reset interval timer
        lastTimeSec = currTimeSec;
        lastTimeMin = currTimeMin;


        /*** Data Collection ***/

        // If using MAX31855 thermocouple, use it to get Temperature
        #ifdef MAX31855
            double extTemperature = thermocouple.readCelsius();     // External Temperature in °C
            double intTemperature = thermocouple.readInternal();    // Internal Temperature in °C
        
        // Otherwise use BME280 (less accurate at low temperatures)
        #else
            double extTemperature = bme.readTemperature();          // External Temperature in °C
            double intTemperature = 0;                              // Internal Temperature in °C
        #endif

        double pressure = bme.readPressure() / 100.0F;  // Pressure in hPa
        double humidity = bme.readHumidity();           // Humidity in %

        // Get battery voltage from BATT pin
        double voltage = analogRead(BATT) * 2.0 * 3.3 / 1024.0; // Battery Voltage in V
        
        // Make sure thermocouple data is valid. If not set to predefined error value (-0.01)
        if (isnan(extTemperature)) {
            extTemperature = -0.01;
        }

        /*** Data Processing ***/

        // Move data to strings (for easy formatting)
        char extT[8];
        char intT[8];
        char pres[8];
        char humi[8];
        char vbat[8];
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

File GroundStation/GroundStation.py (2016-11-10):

'''
Argo 2 Ground Station

Tomas Manterola

Receives data from RFM96W receiver (connected to Arduino/Microcontroller), displays information about capsule, and sends data to HabHub.

Dependencies:
 - crcmod
 - pyqrcode
 - pyserial

'''


import glob
import logging
import re
import sys
import tkFont
import tkMessageBox
import time
import ttk
import urllib
import webbrowser

import Tkinter as tk
from ScrolledText import ScrolledText

# Install missing packages if necessary
try:
    import crcmod.predefined
    import pyqrcode
    import serial

except ImportError:
    try:
        import pip
    except ImportError:
        print("pip must be installed in order to install necessary packages!")
        webbrowser.open("https://pip.pypa.io/en/stable/installing/")
        raw_input("Press any key to exit...")
        quit()
    
    print("Installing necessary packages...")
    pip.main(['install', 'crcmod'])
    pip.main(['install', 'pyqrcode'])
    pip.main(['install', 'pyserial'])
    raw_input("Press any key to exit...")
    quit()


__version__ = "1.1.0"

SERIAL_PORT_SELECT_ERROR    = ["Serial Port Select Error", "Please select valid serial port from the list."]
SERIAL_PORT_START_ERROR     = ["Serial Port Start Error", "Couldn't open serial port. Make sure the device is connected and that the selected serial port is the correct one."]
SERIAL_PORT_READ_ERROR      = ["Serial Port Read Error", "An error occurred while attempting to read data from the serial port. Make sure the device is connected and that the selected serial port is the correct one.\nRetry, or disconnect?"]
SERIAL_PORT_NOT_CONNECTED   = ["Serial Port Not Connected", "To send a command the serial port must be connected. Please plug in the receiver and select it from the list."]

CALLSIGN_LENGTH_ERROR       = ["Callsign Length Error", "Callsign must have 3 or more characters."]

CONNECTION_ERROR            = ["Connection Error", "An error occurred while sending data to HabHub. Check your Internet connection.\nRetry, or set to offline?"]

HELP_MESSAGE                = ["Help", "This program is designed to be used with a LoRa module and an Arduino connected through a serial connection.\nStart by connecting your receiver to your computer using a USB cable."]
ABOUT_MESSAGE               = ["About", "Argo 2 Ground Station\n\nTool for communicating with Argo 2 transceiver and uploading data to HabHub tracker.\n\nAuthor: Tomas Manterola\nVersion: " + __version__ + "\n"]


GENERAL_COMMANDS            = [
                                ["Set Transmit Power",  "0,POWER",  "Set tracker's transmit power to [POWER].\nValue can range from 5 to 23 dBm.\nWARNING: Low TX power could result in signal being too weak to receive."],
                                ["Set GPS Nav Mode",    "1,MODE",   "Set Navigation Mode of tracker's GPS to [MODE].\nValue can be either 0 (Pedestrian) or 1 (Airborne < 1G).\nWarning: GPS must be in Airborne mode at altitudes above 9 km to work."],
                                ["Set GPS Power Mode",  "2,MODE",   "Set Power Mode of tracker's GPS to [MODE].\nValue can be either 0 (Max Performance) or 1 (Power Saving)."],
                                ["Enable Buzzer",       "3,1",      "Enable buzzer to produce sound."],
                                ["Disable Buzzer",      "3,0",      "Disable buzzer to stop producing sound.\nWill only work if buzzer has been previously enabled."],
                                ["Set Tracker State",   "4,STATE",  "Set tracker's state to [STATE], which controls various settings.\nValues can be:\n\t0 - Standby (below 500 m)\n\t1 - Rising (above 500 m and rising)\n\t2 - Falling (High) (above 9,000 m and falling)\n\t3 - Falling (Low) (below 9,000 m and falling)\n\t4 - Landing (below 2,000 and falling)"],
                               #["Set Frequency",       "5,FREQ",   "Set tracker's transmit and receive frequency to [FREQ].\nValue can range from 410.000 to 525.000 MHz.\nWARNING: Receiver's frequency must match tracker's frequency in order to receive messages."],
                                ["Custom Message",      "ID,VALUE", "Send custom message to capsule.\nWARNING: Certain messages could have unwanted effects on the tracker."]
]


global app
global callsign
global callsign_temp
global command_desc
global command_raw
global last_command
global last_data_sentence
global logger
global online
global parsed_data
global rssi
global sent_logger
global ser
global serial_port
global serial_port_wait
global tx_power

global callsign_textbox
global command_listbox
global connect_button
global crc_label
global data_textbox
global qrcode_label

ser = serial.Serial()
serial_port_wait = 1000
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

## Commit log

2016-11-10 Add QR code functionality to Ground Station
    A QR code that users can scan to open a mapping app on their mobile
    device is now displayed on the main screen of the Ground Station
    program.
    The last location received from the tracker is encoded in the
    QR code and displayed on the map. The QR code is updated whenever a new
    valid message is received.
    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
2016-11-10 Change serial port write_timeout to 5 seconds in Ground Station
    This is a minor change to how the program writes to the serial port.
    Before, the serial port would block indefinitely if a write was
    unsuccessful (write_timeout=None). Now the serial port will display an
    error and the program will continue if no data can be sent after 5
    seconds (write_timeout=5).
    [GroundStation.py]
2016-11-10 Bump Ground Station to version 1.1.0
2016-11-10 Add Ground Station README.md
2016-11-11 Merge Feather and Teensy trackers and small changes Merged both Argo2_Tracker_Feather and Argo2_Tracker_Teensy into Argo2_Tracker, keeping original functionality.
    Code was also improved/cleaned-up. The program now uses spaces instead of tabs, unused commented code was removed, and some comments/messages were improved.
    Main changes:
    - Merged Feather and Teensy trackers into one
    - Cleaned up code (all tabs now spaces, removed unused code)
    - Improved state transition values for RISING and FALLING
    - Debug messages now disabled by default
2016-11-19 Fix #2 and change default settings
    Fix pin assignment issue with Teensy to Feather adapter, as well as
    changing various defaults in the tracker.
    Changes:
    - Pins when using Teensy changed
    - Feather is now default board (previously Teensy)
    - MAX31855 now disabled (SPI issues)
    - Callsign must be set for code to run (to prevent mistakes)
    - Debug messages now ON by default
    [Argo2_Tracker.ino, Argo2_Tracker_Feather.ino, Argo2_Tracker_Teensy.ino]

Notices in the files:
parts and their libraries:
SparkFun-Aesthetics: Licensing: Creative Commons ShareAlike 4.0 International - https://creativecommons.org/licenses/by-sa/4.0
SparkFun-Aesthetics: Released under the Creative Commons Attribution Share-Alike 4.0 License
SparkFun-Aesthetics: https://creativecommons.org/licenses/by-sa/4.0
